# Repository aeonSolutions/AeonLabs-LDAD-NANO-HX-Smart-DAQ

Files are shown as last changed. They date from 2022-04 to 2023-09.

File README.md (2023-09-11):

[PCB-Prototyping-Catalogue](https://github.com/aeonSolutions/PCB-Prototyping-Catalogue)  >>  [Laboratory Automation](https://github.com/aeonSolutions/PCB-Prototyping-Catalogue/tree/main/Laboratory%20Automation) >>  [Smart DAQ](https://github.com/aeonSolutions/PCB-Prototyping-Catalogue/tree/main/Smart%20DAQ)  >>   [12-bit Smart DAQs](https://github.com/aeonSolutions/PCB-Prototyping-Catalogue/tree/main/Smart%20DAQ/12-bit)  >>  LDAD NANO HX Smart DAQ

<br>

#  LDAD NANO HX Smart DAQ
This repo contains the KiCad files for the  AeonLabs  LDAD NANO for strain sensing / weight measurements and more than 20 other sensors compatible with I2C protocol communication. 
 
*Don't forget to LIKE , SHARE and subscribe the free whatsApp group* and if you liked this PCB consider buying me a cup of coffee. Links below.




###   Status

Fully working.

## Download options
Download this repository if you need the KiCad Files or, download the Gerber files in the release section of this repository

## Liked it ? Get a Free PCB for yourself
Send me your Device or hardware and i will design a custom PCB for it. Free of charge. Contact-me on WhatsApp or email for more info. 

## Q&A WhatsApp Group
If you have any Questions or simply  like this kind of projects and want to stay updated with the latest research ideas and prototypes during the day and week, join the WhatsApp Group
[LDAD Lab & Prototyping](https://chat.whatsapp.com/FkNC7u83kuy2QRA5sqjBVg)

## Fully assembled PCB
Alternatively, and if you do not want to build a PCB by yourself and like to buy one, you can do it here:

(https://www.tindie.com/stores/aeonlabs/)

The price will be around 30eur plus postage fees.
(I will also deliver the assembled PCB with all the components in place at a fair aditonal cost).

#### Be supportive of my dedication and work towards technology education and buy me a coffee. Link below.
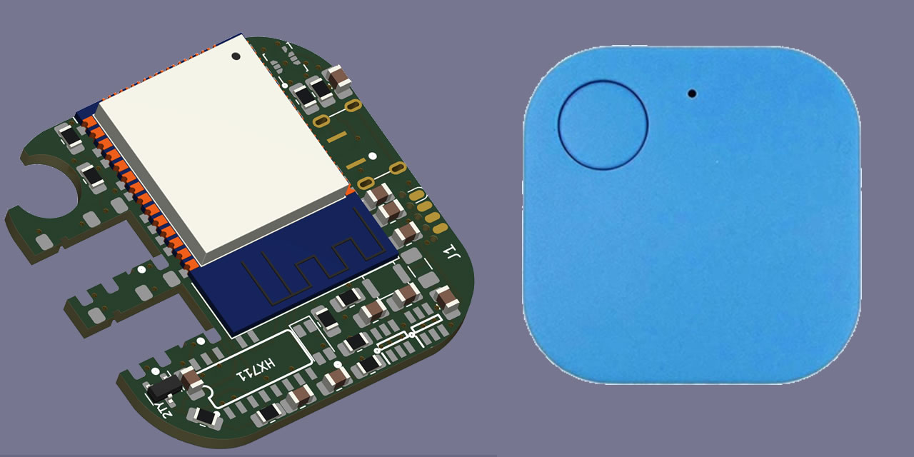
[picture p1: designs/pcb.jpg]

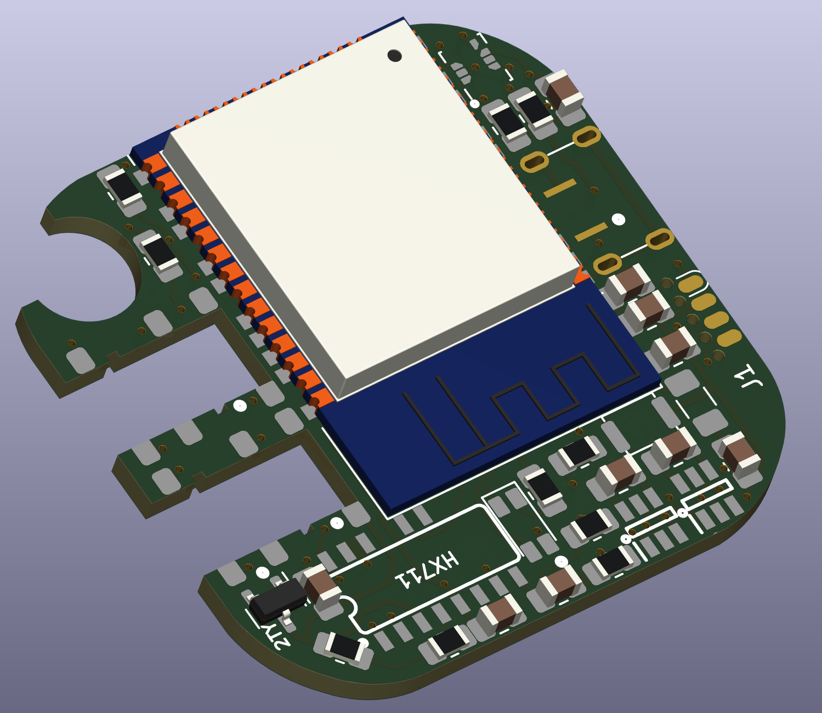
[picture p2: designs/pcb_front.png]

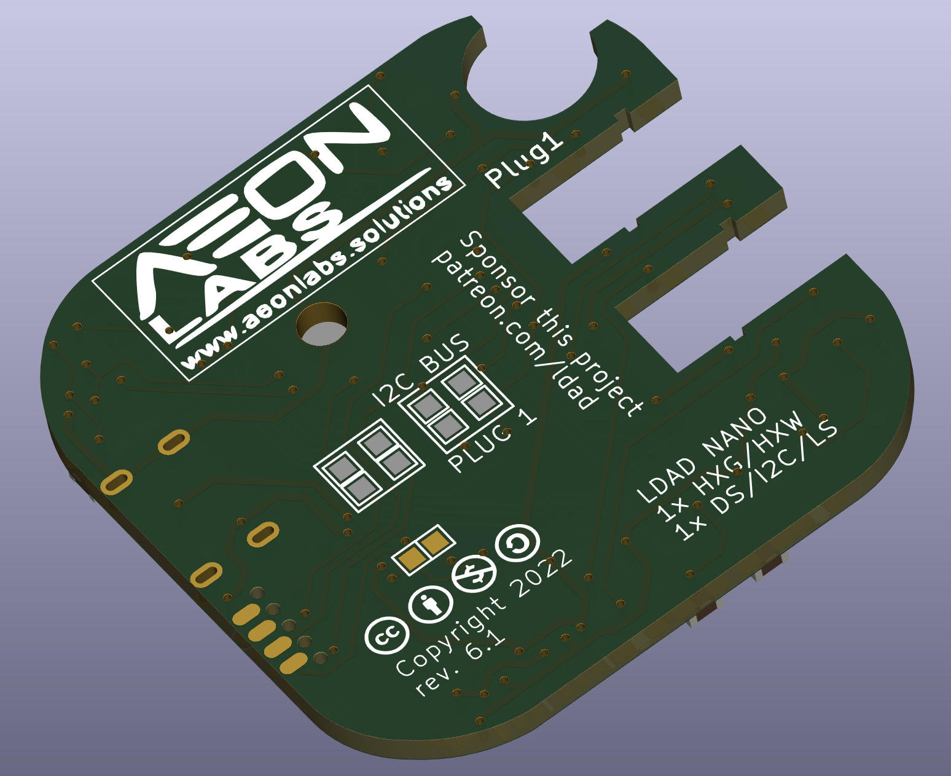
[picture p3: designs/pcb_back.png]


________________________________________________________________________________________________________________
## [Go back to main catalogue page](https://github.com/aeonSolutions/PCB-Prototyping-Catalogue)
________________________________________________________________________________________________________________

## PCB Parts list
- DC2DC converter HX4002B x2 : https://s.click.aliexpress.com/e/_Ak7IPx
- Capacitor 100nF SMD 1206 : https://s.click.aliexpress.com/e/_AVdmzr
- Capacitor 2.2uF SMD 1206 : https://s.click.aliexpress.com/e/_AVdmzr
- Resistor SMD 1206 330R x3 : https://s.click.aliexpress.com/e/_A7OXrR
- ESP32 WROOM32 x1 : https://s.click.aliexpress.com/e/_AF7N6l
- LED RGB x1: https://s.click.aliexpress.com/e/_AccXHT

## Firmware Download 
one can use the PCB in the repository [AeonLabs-MCU-Burner-USB-to-UART-TTL](https://github.com/aeonSolutions/AeonLabs-MCU-Burner-USB-to-UART-TTL) to program the ESP32 WROOM32 MCU on this PCB.

______________________________________________________________________________________________________________________________

### License
2022 Creative Commons Attribution-NonCommercial-ShareAlike 4.0 International

https://creativecommons.org/licenses/by-nc-sa/4.0/

### Own a copy of this work
if you like to own a copy of this work, you can buy it as a NFT or Ethereum. contact me for more details at mtpsilva@gmail.com

=====================================================================================
### Share this PCB board files
[](https://twitter.com/intent/tweet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)

<a href="https://stackexchange.com/users/18907312/miguel-silva">profile for Miguel Silva on Stack Exchange, a network of free, community-driven Q&A sites</a>

### Be supportive of my dedication and work towards technology education and buy me a coffee

[](https://www.buymeacoffee.com/migueltomas)

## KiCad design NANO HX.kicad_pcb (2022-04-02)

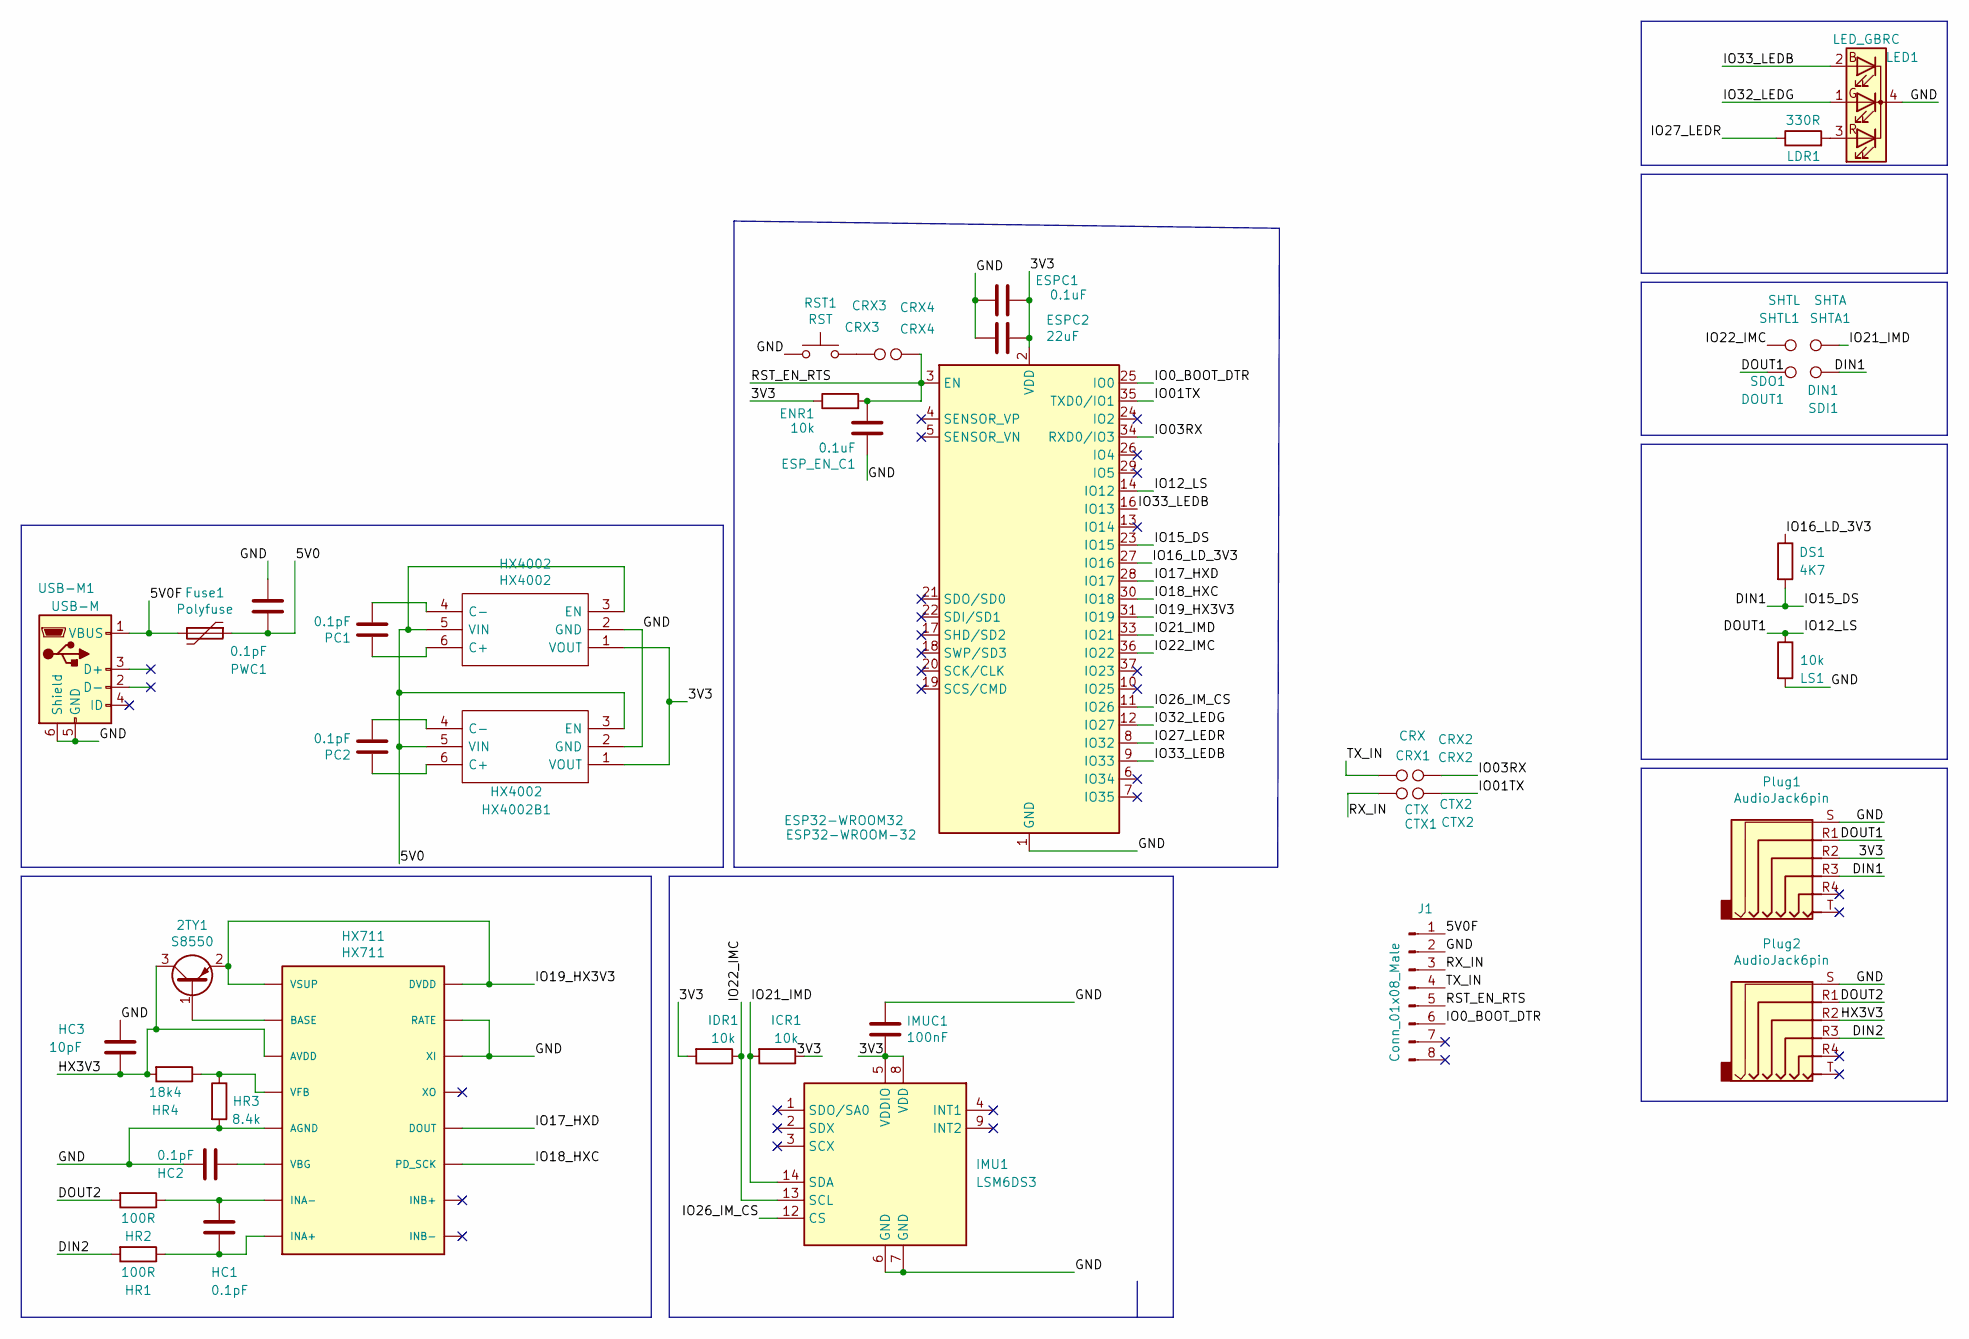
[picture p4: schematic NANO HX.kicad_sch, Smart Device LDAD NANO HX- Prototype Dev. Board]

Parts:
2TY1: S8550; SOT-23
CRX1: CRX; TestPoint_Pad_1.0x1.0mm
CRX2: CRX2; TestPoint_Pad_1.0x1.0mm
CRX3: CRX3; TestPoint_Pad_1.0x1.0mm
CRX4: CRX4; TestPoint_Pad_1.0x1.0mm
CTX1: CTX; TestPoint_Pad_1.0x1.0mm
CTX2: CTX2; TestPoint_Pad_1.0x1.0mm
DS1: 4K7; R_0805_2012Metric_Pad1.20x1.40mm_HandSolder
ENR1: 10k; R_0805_2012Metric_Pad1.20x1.40mm_HandSolder
ESP32-WROOM32: ESP32-WROOM-32
ESPC1: 0.1uF; C_0805_2012Metric_Pad1.18x1.45mm_HandSolder
ESPC2: 22uF; C_0805_2012Metric_Pad1.18x1.45mm_HandSolder
ESP_EN_C1: 0.1uF; C_0805_2012Metric_Pad1.18x1.45mm_HandSolder
Fuse1: Polyfuse; Fuse_1206_3216Metric
HC1, HC2: 0.1pF; C_0805_2012Metric_Pad1.18x1.45mm_HandSolder
HC3: 10pF; C_0805_2012Metric_Pad1.18x1.45mm_HandSolder
HR1, HR2: 100R; R_0805_2012Metric_Pad1.20x1.40mm_HandSolder
HR3: 8.4k; R_0805_2012Metric_Pad1.20x1.40mm_HandSolder
HR4: 18k4; R_0805_2012Metric_Pad1.20x1.40mm_HandSolder
HX711: HX711; SO16
HX4002, HX4002B1: HX4002; HX4002 SOT95 P280X125-6N; Manufacturer_Part_Number HX4002
ICR1: 10k; R_0805_2012Metric_Pad1.20x1.40mm_HandSolder
IDR1: 10k; R_0805_2012Metric_Pad1.20x1.40mm_HandSolder
IMU1: LSM6DS3; LGA-14_3x2.5mm_P0.5mm_LayoutBorder3x4y
IMUC1: 100nF; C_0805_2012Metric_Pad1.18x1.45mm_HandSolder
J1: Conn_01x08_Male; SOIC_clipProgSmall
LDR1: 330R; R_0805_2012Metric_Pad1.20x1.40mm_HandSolder
LED1: LED_GBRC; LED_1206_3210_RGB_Metric
LS1: 10k; R_0805_2012Metric_Pad1.20x1.40mm_HandSolder
PC1, PC2: 0.1pF; C_0805_2012Metric_Pad1.18x1.45mm_HandSolder
PWC1: 0.1pF; C_0805_2012Metric_Pad1.18x1.45mm_HandSolder
Plug1, Plug2: AudioJack6pin; Jack 2.5mm jack socket 6pin L10.5 w5.8 h3.2
RST1: RST; SW_Push_SPST_NO_Alps_SKRK AliExpress
SDI1: DIN1; TestPoint_Pad_1.0x1.0mm
SDO1: DOUT1; TestPoint_Pad_1.0x1.0mm
SHTA1: SHTA; TestPoint_Pad_1.0x1.0mm
SHTL1: SHTL; TestPoint_Pad_1.0x1.0mm
USB-M1: USB-M; Micro_USB_pcb_socket_5pin_4weld_points

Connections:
/3V3: ENR1.1, ESP32-WROOM32.2 (VDD), ESPC1.1, ESPC2.1, HX4002.1 (VOUT), HX4002B1.1 (VOUT), ICR1.1, IDR1.2, IMU1.5 (VDDIO), IMU1.8 (VDD), IMUC1.2, Plug1.R2
/5V0: Fuse1.1, HX4002.3 (EN), HX4002.5 (VIN), HX4002B1.3 (EN), HX4002B1.5 (VIN), PWC1.1
/5V0F: Fuse1.2, J1.1, USB-M1.1 (VBUS)
/DIN1: DS1.2, ESP32-WROOM32.23 (IO15), Plug1.R3, SDI1.1
/DIN2: HR1.2, Plug2.R3
/DOUT1: ESP32-WROOM32.14 (IO12), LS1.1, Plug1.R1, SDO1.1
/DOUT2: HR2.2, Plug2.R1
/GND: ESP32-WROOM32.1 (GND), ESP32-WROOM32.15 (GND), ESP32-WROOM32.38 (GND), ESP32-WROOM32.39 (GND), ESPC1.2, ESPC2.2, ESP_EN_C1.1, HC2.2, HC3.1, HR3.2, HX711.5 (AGND), HX711.14 (XI), HX711.15 (RATE), HX4002.2 (GND), HX4002B1.2 (GND), IMU1.6 (GND), IMU1.7 (GND), IMUC1.1, J1.2, LED1.4 (K), LS1.2, PWC1.2, Plug1.S, Plug2.S, RST1.1, USB-M1.5 (GND), USB-M1.6 (Shield)
/HX3V3: 2TY1.3 (C), HC3.2, HR4.2, HX711.3 (AVDD), Plug2.R2
/IO0_BOOT_DTR: ESP32-WROOM32.25 (IO0), J1.6
/IO01TX: CTX2.1, ESP32-WROOM32.35 (TXD0/IO1)
/IO03RX: CRX2.1, ESP32-WROOM32.34 (RXD0/IO3)
/IO16_LD_3V3: DS1.1, ESP32-WROOM32.27 (IO16)
/IO17_HXD: ESP32-WROOM32.28 (IO17), HX711.12 (DOUT)
/IO18_HXC: ESP32-WROOM32.30 (IO18), HX711.11 (PD_SCK)
/IO19_HX3V3: 2TY1.2 (E), ESP32-WROOM32.31 (IO19), HX711.1 (VSUP), HX711.16 (DVDD)
/IO21_IMD: ESP32-WROOM32.33 (IO21), ICR1.2, IMU1.14 (SDA), SHTA1.1
/IO22_IMC: ESP32-WROOM32.36 (IO22), IDR1.1, IMU1.13 (SCL), SHTL1.1
/IO26_IM_CS: ESP32-WROOM32.11 (IO26), IMU1.12 (CS)
/IO27_LEDR: ESP32-WROOM32.8 (IO32), LDR1.1
/IO32_LEDG: ESP32-WROOM32.12 (IO27), LED1.1 (GA)
/IO33_LEDB: ESP32-WROOM32.9 (IO33), ESP32-WROOM32.16 (IO13), LED1.2 (BA)
/RST_EN_RTS: CRX4.1, ENR1.2, ESP32-WROOM32.3 (EN), ESP_EN_C1.2, J1.5
/RX_IN: CTX1.1, J1.3
/TX_IN: CRX1.1, J1.4
unnamed: 2TY1.1 (B), HX711.2 (BASE)
unnamed: CRX3.1, RST1.2
unnamed: HC1.1, HR2.1, HX711.7 (INA-)
unnamed: HC1.2, HR1.1, HX711.8 (INA+)
unnamed: HC2.1, HX711.6 (VBG)
unnamed: HR3.1, HR4.1, HX711.4 (VFB)
unnamed: HX4002.4 (C-), PC1.2
unnamed: HX4002.6 (C+), PC1.1
unnamed: HX4002B1.4 (C-), PC2.2
unnamed: HX4002B1.6 (C+), PC2.1
unnamed: LDR1.2, LED1.3 (RA)

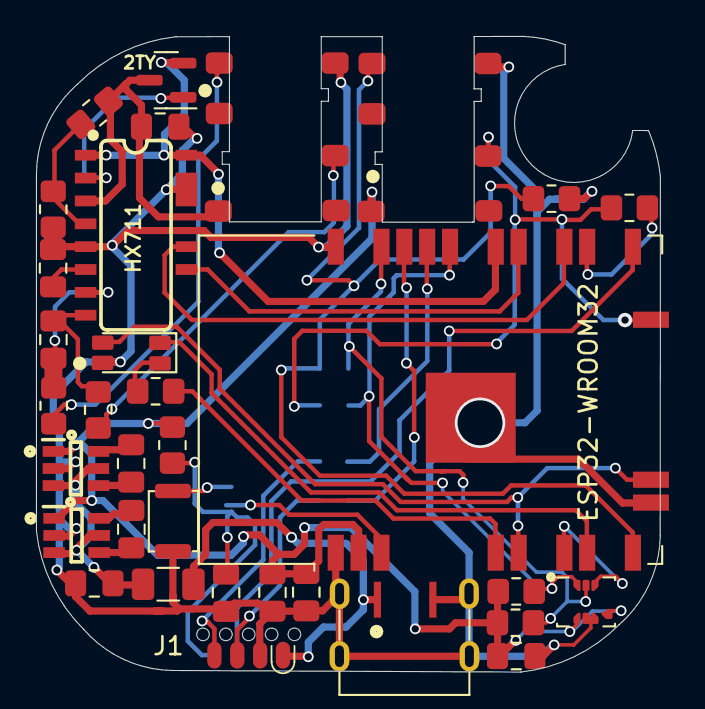
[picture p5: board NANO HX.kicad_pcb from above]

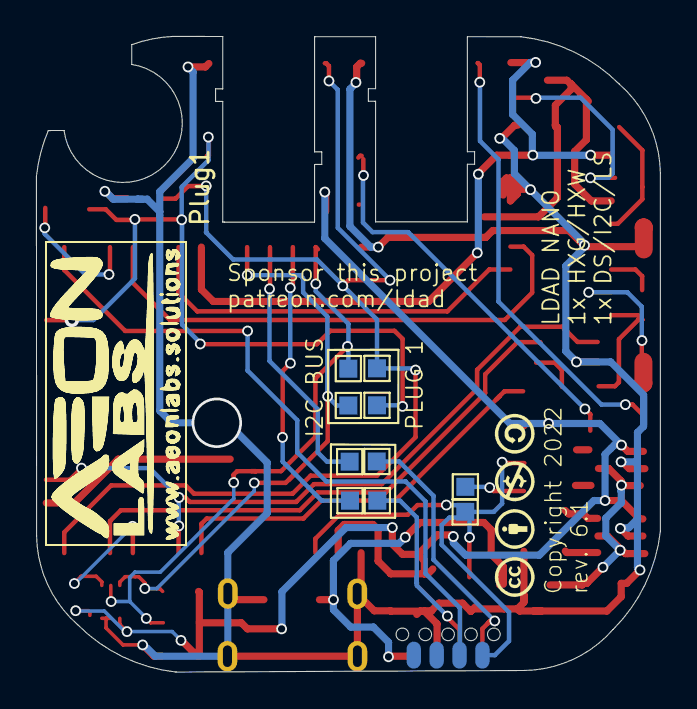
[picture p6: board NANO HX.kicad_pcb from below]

Board: 2 copper layers, 34.7 x 35.3 mm, 43 parts (10 on the bottom side), 36 nets.

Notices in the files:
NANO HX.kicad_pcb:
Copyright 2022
